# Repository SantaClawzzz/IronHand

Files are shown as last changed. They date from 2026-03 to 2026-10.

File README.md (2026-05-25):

# Ironhand keyboard

keyboard

A full-sized keyboard in ZMK. Features a colored TFT screen, encoder, bluetooth connection and a battery.<br>
Numpad is on the left side and switches are easily replaceable with hotswap sockets. Tarkov themed.

* Keyboard specs:
  * 1 nice!nano v2 or nrf52840 pro Micro devkit
  * 1 MCP23S17-E_SO
  * 102 switches (MX)
  * 102 DO-35 diodes (1N4148)
  * 60 100nF 0603 capacitors (Any 100nF)
  * 103 LEDs (WS2812-2020) [One LED under the MCU]
  * One 2000mAh 3.7V LiPo Battery [Bridge the Charging pads under nice!nano]
  * 1 battery connector (JST PH 2.0)
  * 1 0.96" TFT SPI screen
  * 1 encoder
  * 1 button (TL3305A, optional)

## Electronics

The PCB order can be expensive, mostly shipping due to the size. I recommend ordering at least 10 (5 is minimum).<br>
The soldering is mostly fine, hotswap sockets and capacitors are easy but the LEDs are a pain.<br>
My recommendation:
* Solder one corner of the 4 pads on the entire row
* Take a LED and match the polarity
* Solder only by the corner for the entire row
* Then go backwards and solder the same side other corner, turn it and do the other side
  * Easier to do one side at a time
  * Holding the solder iron in the right hand do the right side of the LED
  * Then turn it 180 degrees and solder the other side
  * But to each their own
* the MCP soldering is basically the same, do one corner, align it, then solder the rest of the pins
* Keep in mind that the devkit has a pad under it that needs to be bridged to charge faster if you have a battery bigger than 500mAh!
* Also there is a LED under the devkit on the PCB, solder them first then the devkit on it.
* Otherwise without a desolder gun, you're gonna have a bad time.

## Mechanics

If you wish to change the project files, go ahead. It was designed in Fusion.
Printed with PETG and mostly default settings.
Two halves were attached with a metal plate and staples melted into the PETG halves.

## Firmware

* Connect USB-C
* Open ***Actions*** tab in this github repository
* Download the firmware <br>
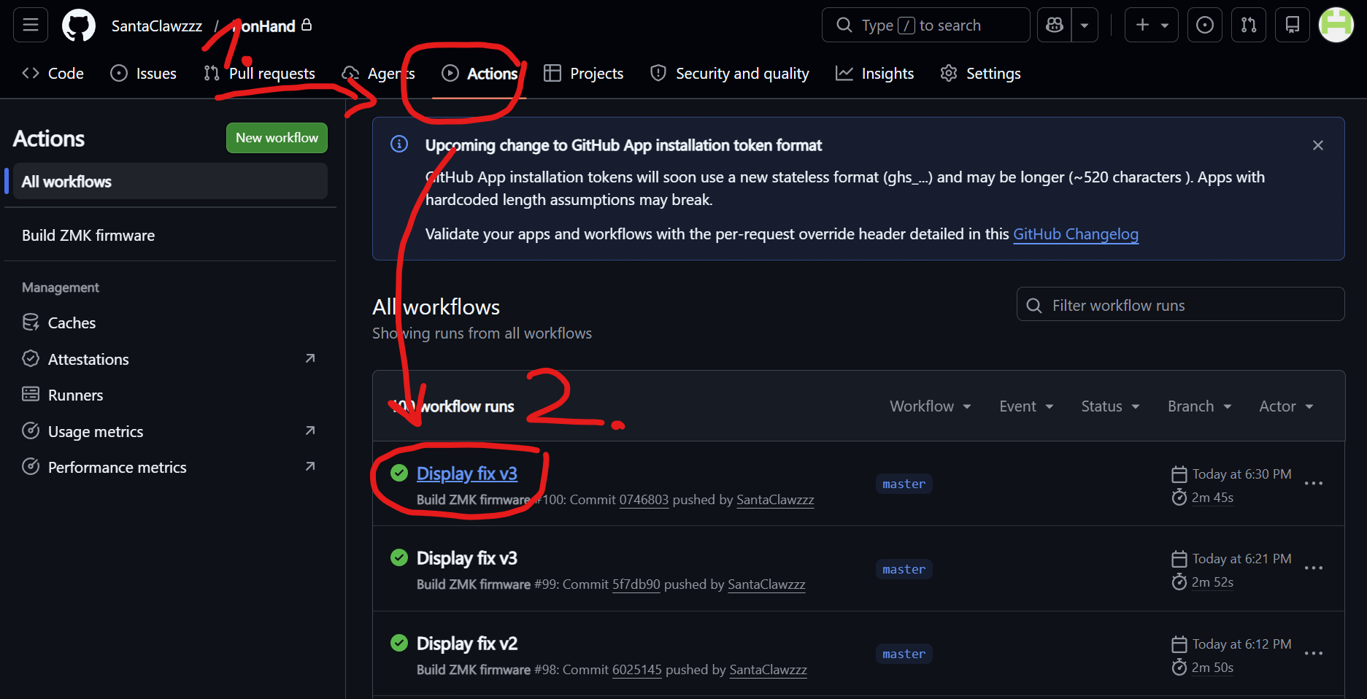
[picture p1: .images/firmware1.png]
firmware1

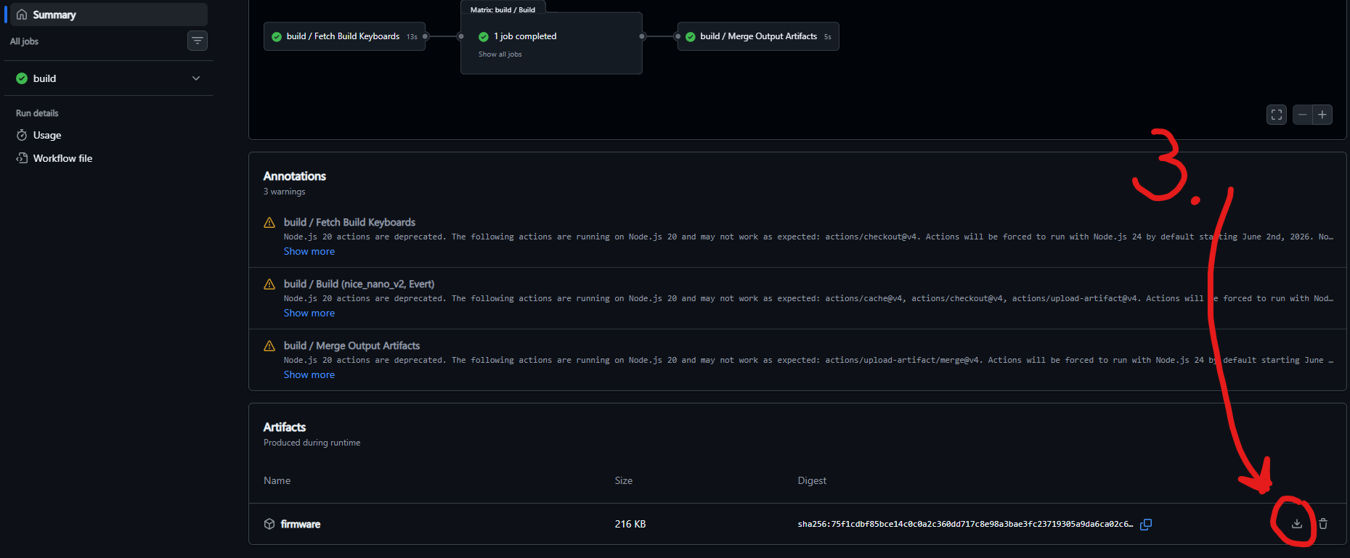
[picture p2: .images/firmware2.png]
firmware2

* Double press the reset button on the keyboard and drop the file into the file system
  * If you are in bootloader the red LED will constantly blink (nrf pro Micro devkit)

## Notes to consider when building custom keyboard

Read the documentation thoroughly, the directory of the files is VERY IMPORTANT.<br>
It's much more restrict than QMK so it will take some time.<br>
Just try to get it to compile wihtout much code and then start adding features.

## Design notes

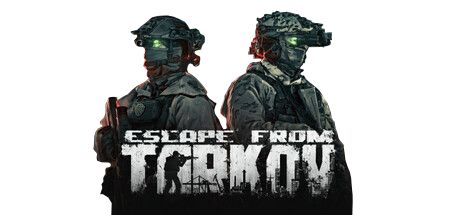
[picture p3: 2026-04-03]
Electronics/v1/Expo/escapefromtarkov.jpg

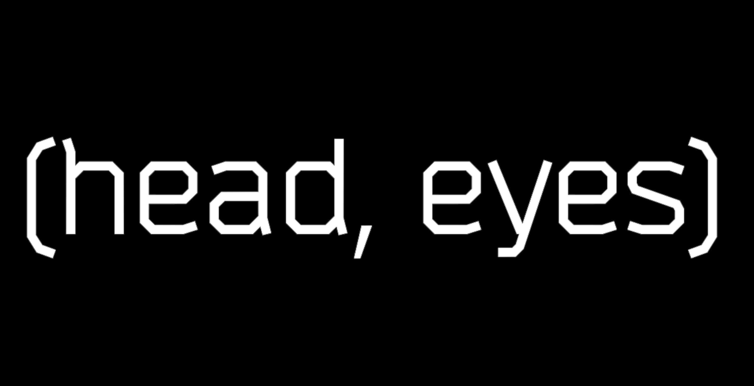
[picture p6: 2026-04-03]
Electronics/v1/Expo/headeyes.png

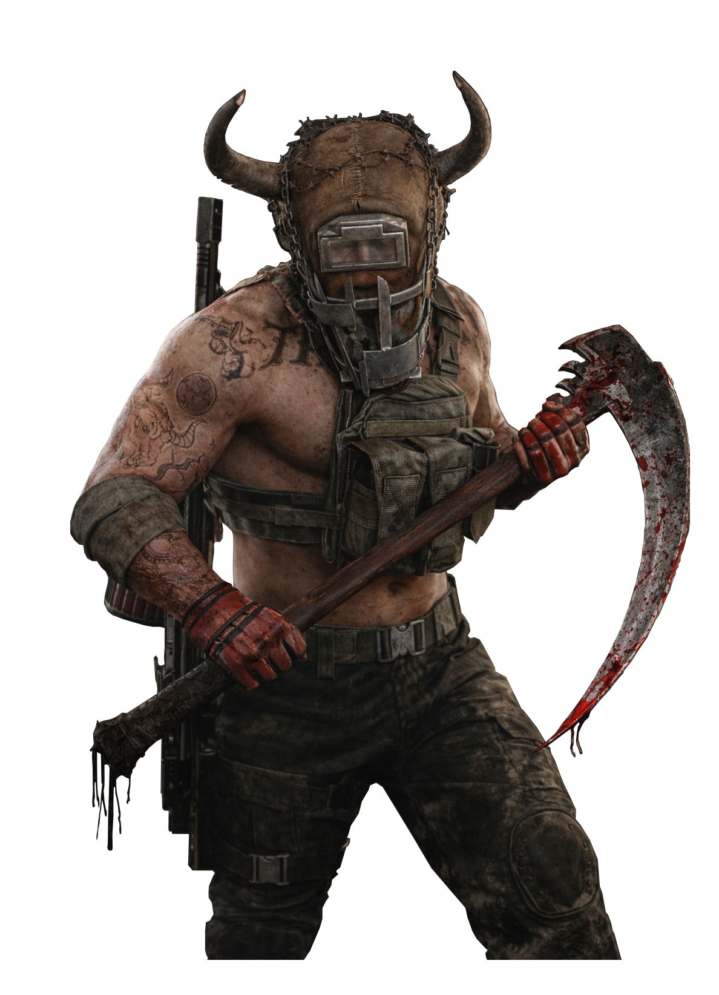
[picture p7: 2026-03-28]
Electronics/v1/Expo/killa.jpg

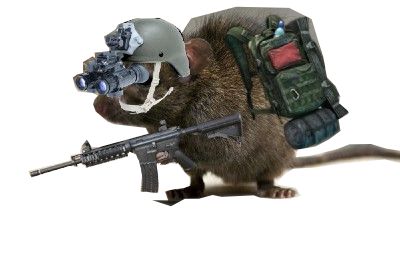
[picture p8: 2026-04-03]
Electronics/v1/Expo/Rat.jpg

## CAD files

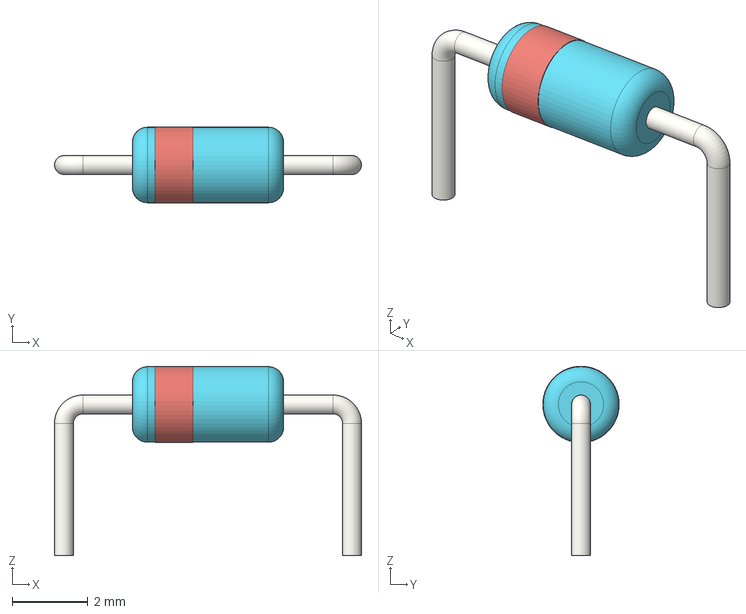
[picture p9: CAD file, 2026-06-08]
Electronics/v1/IronHand_v1/Components/3DModels/Diode_DO-35.step
8.12 x 2.02 x 5.01 mm

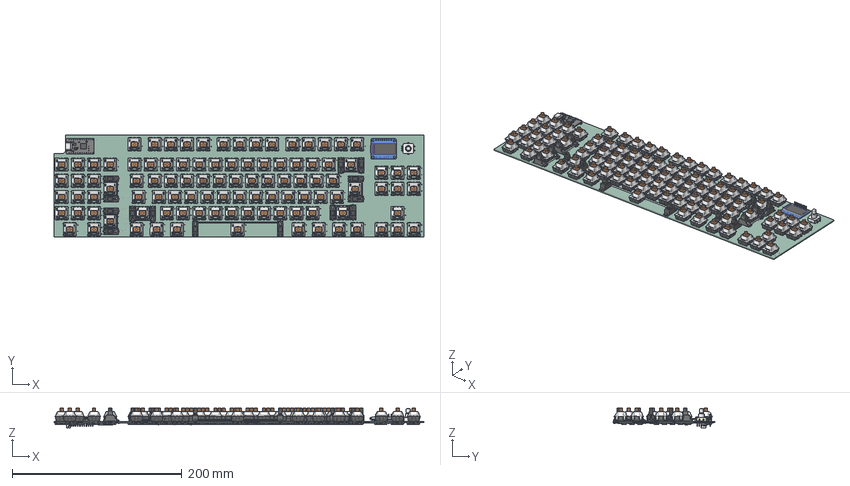
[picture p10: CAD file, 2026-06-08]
Electronics/v1/IronHand_v1/Output/pcb.step
435.3 x 120.0 x 23.1 mm
Hotswap_MX x 102
MX_PCB x 102
PinHeader_1x12_P2.54mm_Vertical.step
User Library-TYPE-C-31-M-14.step
MICRO_603 resistor 102
MICRO_stackable header pin x 12
MICRO_stackable header 12
micro_crystal 5x3
MICRO_led
micro_MIC5219
Stabilizer_MX_6.25u
Stabilizer_MX_2.00u x 6
PinHeader_1x08_P2.54mm_Vertical
0.96 - IPS LCD - ST7735S
Case003
Mount001
Case002
Case01
Leg001
Shaft002 x 2
Shaft001 x 2
Shaft003 x 2
Leg002 x 2
Leg003 x 2
Leg005 x 2
Leg004
Mount002
Diode_DO-35 x 3
SOIC28-W_MC_MCH
JST_PH_B2B-PH-K_1x02_P2.00mm_Vertical
SW_SPST_TL3305A
IronHand_v1_PCB

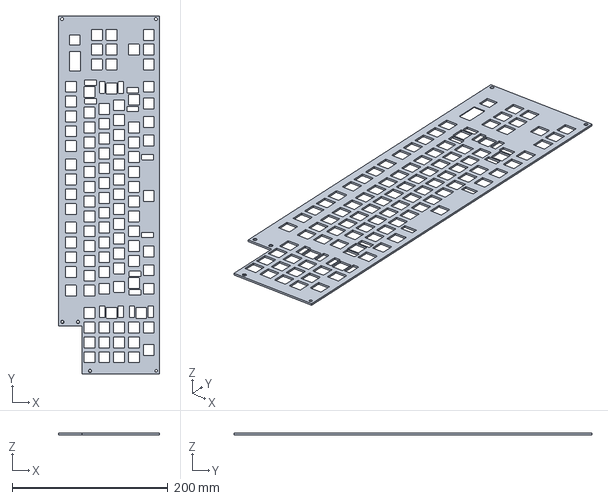
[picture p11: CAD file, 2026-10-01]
Mechnaics/PCBPlate.step
129.7 x 460.0 x 2.00 mm

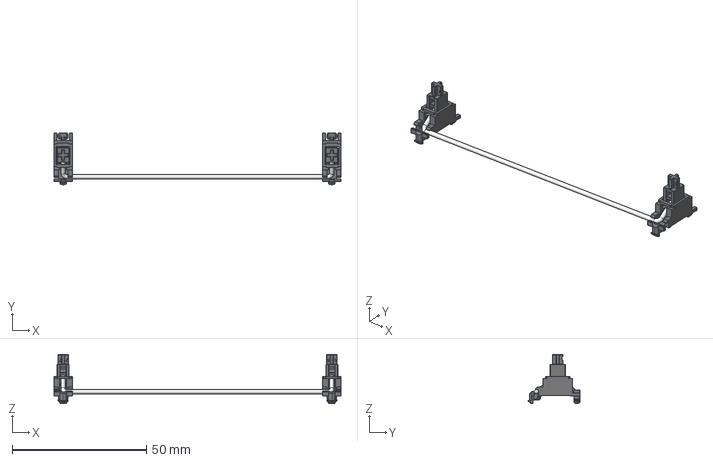
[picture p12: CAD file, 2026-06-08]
Electronics/v1/IronHand_v1/Components/3DModels/Stabilizer_MX_6.25u.step
106.8 x 19.2 x 18.3 mm

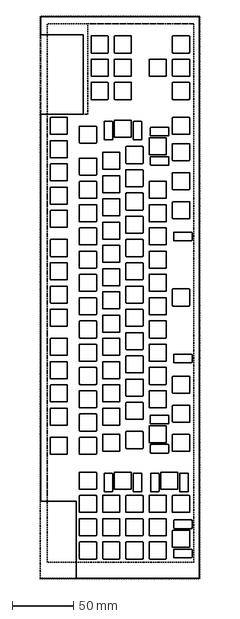
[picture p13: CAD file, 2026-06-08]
Electronics/v1/IronHand_v1/Output/IronHandPCBPlate.dxf
131.0 x 461.0 mm

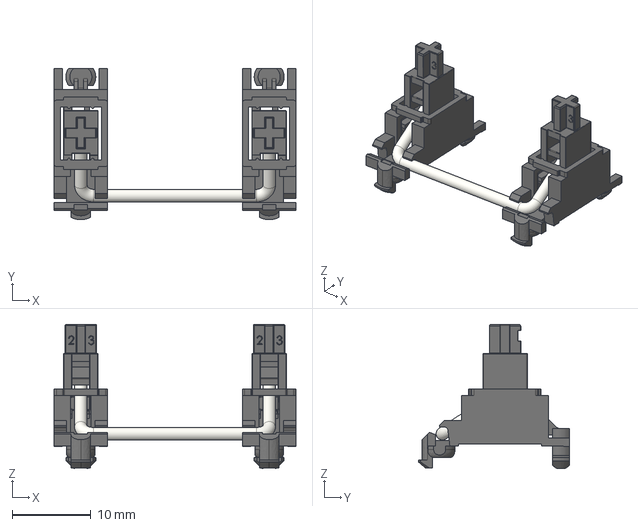
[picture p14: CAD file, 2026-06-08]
Electronics/v1/IronHand_v1/Components/3DModels/Stabilizer_MX_2.00u.step
30.7 x 19.2 x 18.3 mm

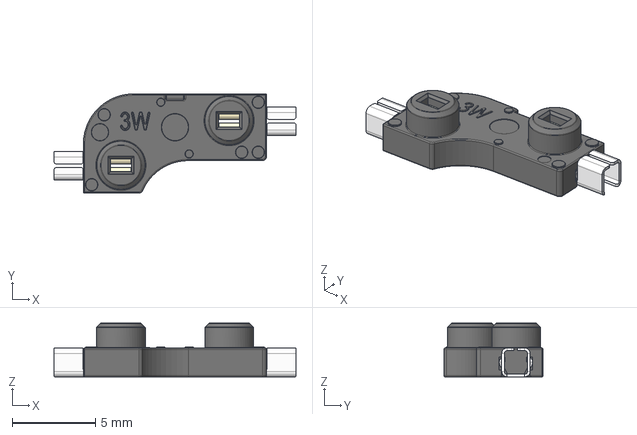
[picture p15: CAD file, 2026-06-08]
Electronics/v1/IronHand_v1/Components/3DModels/Hotswap_MX.step
14.5 x 5.95 x 3.22 mm

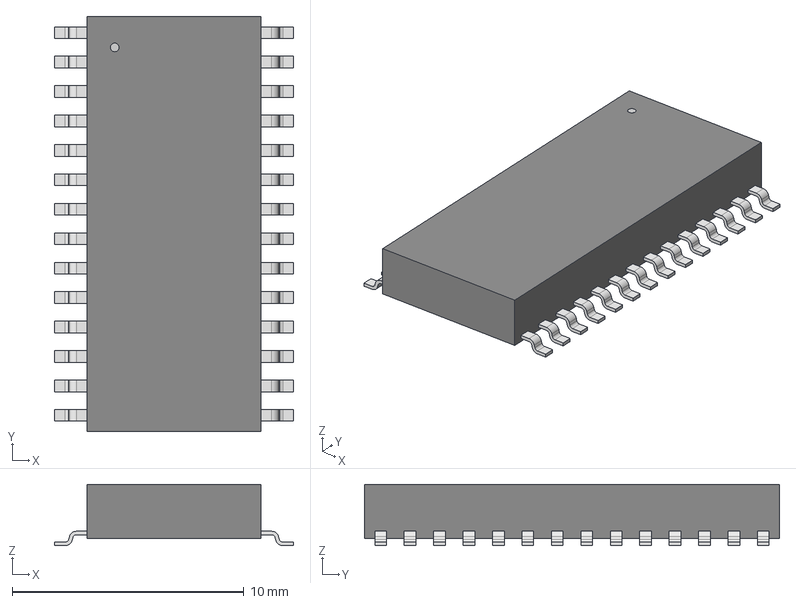
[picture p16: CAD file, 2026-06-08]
Electronics/v1/IronHand_v1/Components/3DModels/SOIC28-W_MC_MCH.step
10.3 x 17.9 x 2.64 mm

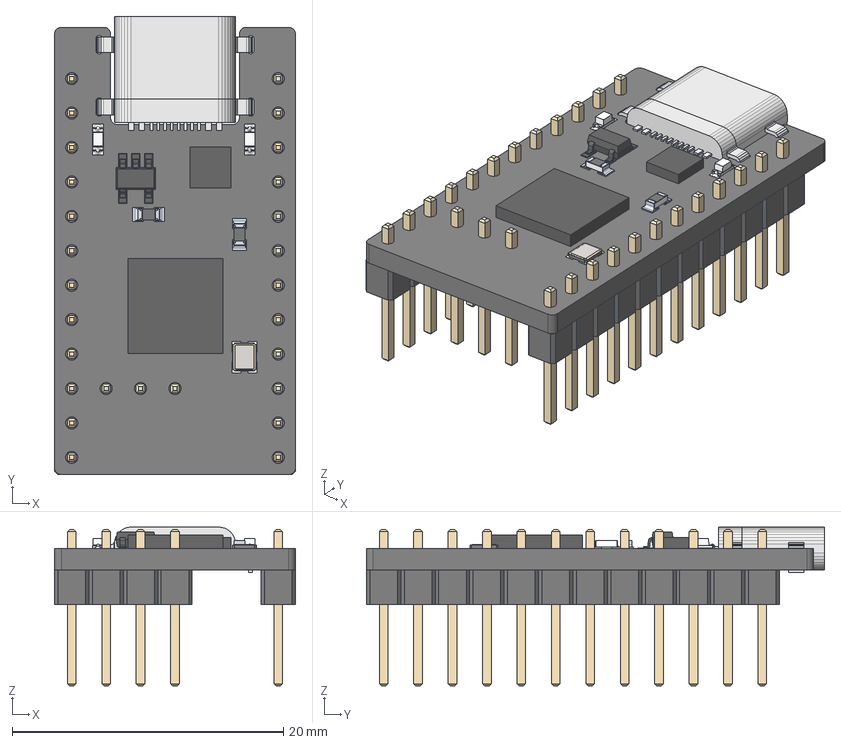
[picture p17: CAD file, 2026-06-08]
Electronics/v1/IronHand_v1/Components/3DModels/Nice_Nano_V2.step
17.8 x 33.8 x 11.7 mm
PinHeader_1x12_P2.54mm_Vertical.step
User Library-TYPE-C-31-M-14.step
MICRO_603 resistor 102
MICRO_stackable header pin x 12
MICRO_stackable header 12
micro_crystal 5x3
MICRO_led
micro_MIC5219

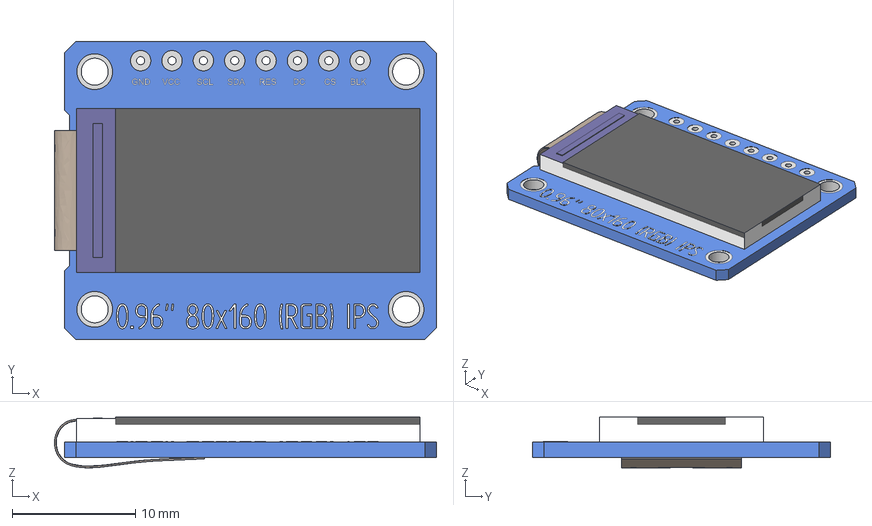
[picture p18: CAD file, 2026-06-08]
Electronics/v1/IronHand_v1/Components/3DModels/0.96 - IPS LCD - ST7735S.stp
30.9 x 24.1 x 4.11 mm

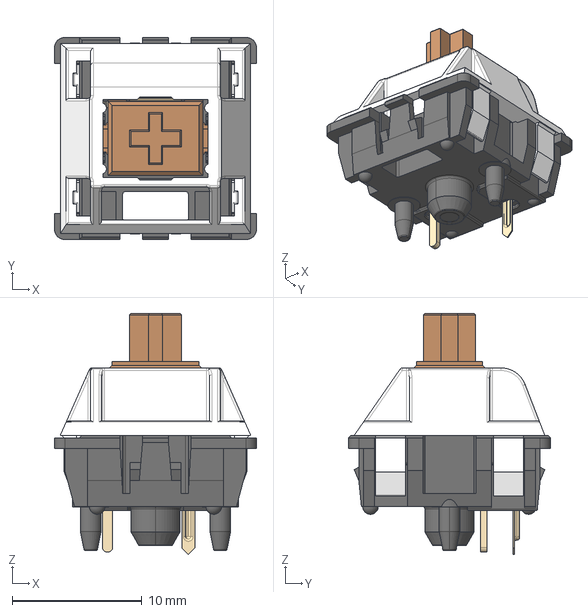
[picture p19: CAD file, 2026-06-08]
Electronics/v1/IronHand_v1/Components/3DModels/MX_PCB.step
15.6 x 15.6 x 18.6 mm

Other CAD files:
Mechnaics/PCBPlate.f3d

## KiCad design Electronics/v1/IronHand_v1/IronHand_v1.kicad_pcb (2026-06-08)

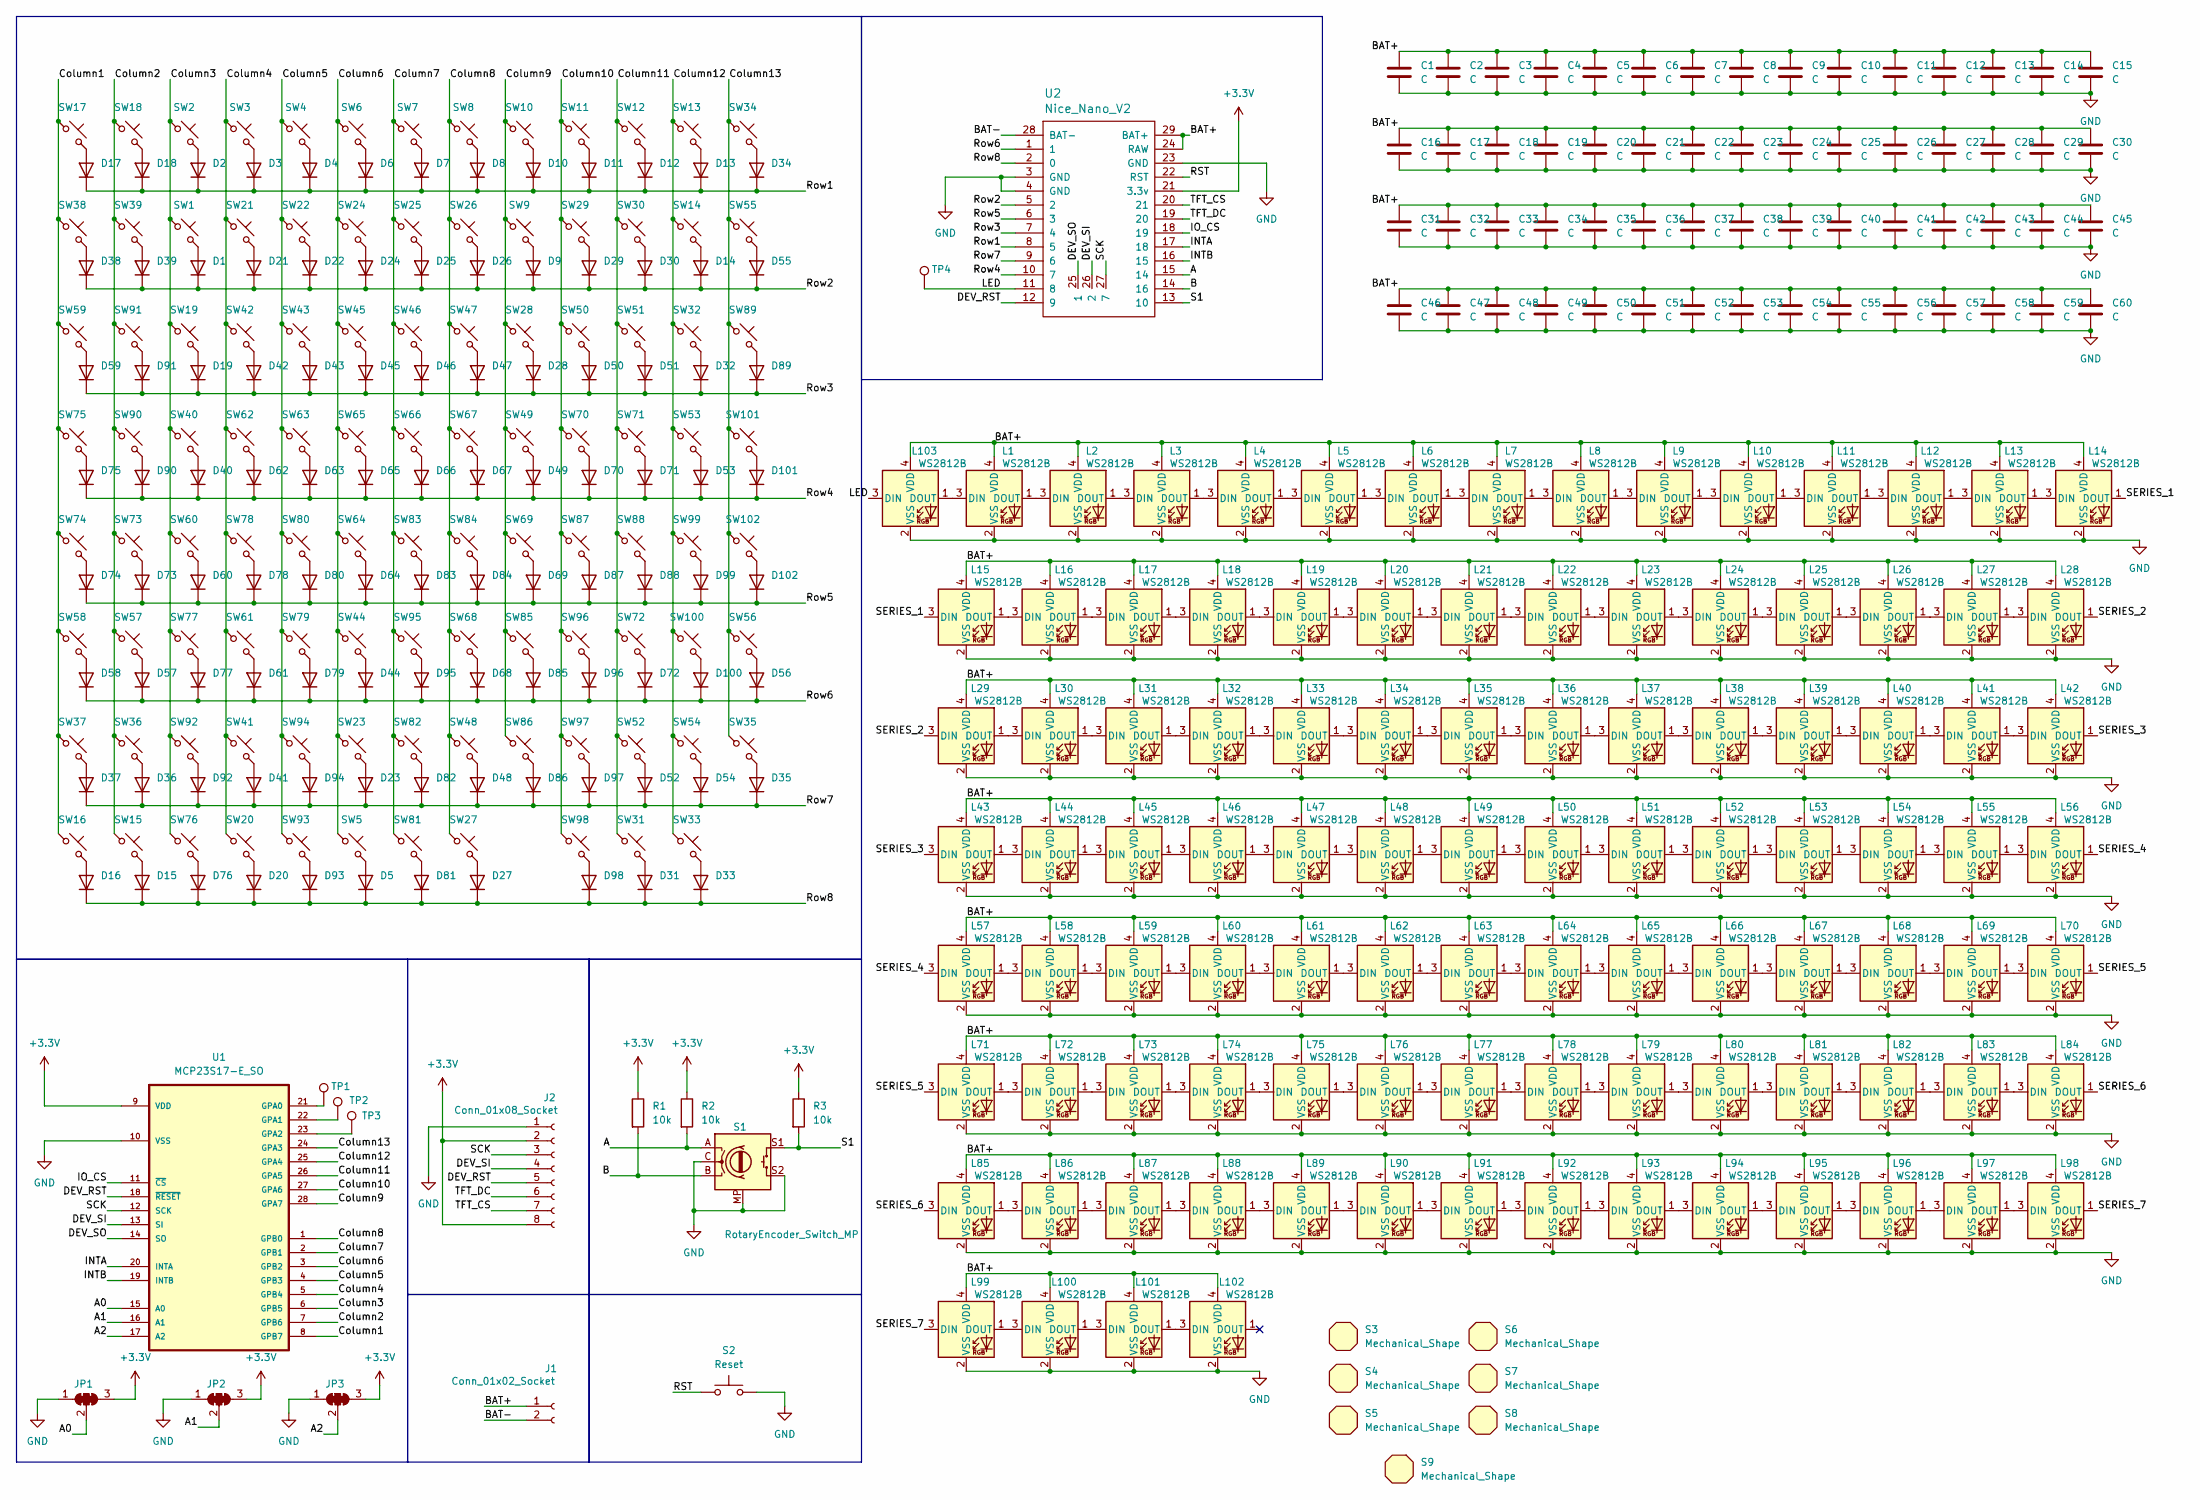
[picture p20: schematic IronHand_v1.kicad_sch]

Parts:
C1, C2, C3, C4, C5, C6, C7, C8, C9, C10, C11, C12, C13, C14, C15, C16, C17, C18, C19, C20, C21, C22, C23, C24, C25, C26, C27, C28, C29, C30, C31, C32, C33, C34, C35, C36, C37, C38, C39, C40, C41, C42, C43, C44, C45, C46, C47, C48, C49, C50, C51, C52, C53, C54, C55, C56, C57, C58, C59, C60: C; C_0603_1608Metric_Pad1.08x0.95mm_HandSolder
D1, D2, D3, D4, D5, D6, D7, D8, D9, D10, D11, D12, D13, D14, D15, D16, D17, D18, D19, D20, D21, D22, D23, D24, D25, D26, D27, D28, D29, D30, D31, D32, D33, D34, D35, D36, D37, D38, D39, D40, D41, D42, D43, D44, D45, D46, D47, D48, D49, D50, D51, D52, D53, D54, D55, D56, D57, D58, D59, D60, D61, D62, D63, D64, D65, D66, D67, D68, D69, D70, D71, D72, D73, D74, D75, D76, D77, D78, D79, D80, D81, D82, D83, D84, D85, D86, D87, D88, D89, D90, D91, D92, D93, D94, D95, D96, D97, D98, D99, D100, D101, D102: D; Diode_DO-35
J1: Conn_01x02_Socket; JST_PH_B2B-PH-K_1x02_P2.00mm_Vertical
J2: Conn_01x08_Socket; PinHeader_1x08_P2.54mm_Vertical
JP1, JP2, JP3: SolderJumper_3_Bridged123; SolderJumper-3_P2.0mm_Open_TrianglePad1.0x1.5mm_NumberLabels
L1, L2, L3, L4, L5, L6, L7, L8, L9, L10, L11, L12, L13, L14, L15, L16, L17, L18, L19, L20, L21, L22, L23, L24, L25, L26, L27, L28, L29, L30, L31, L32, L33, L34, L35, L36, L37, L38, L39, L40, L41, L42, L43, L44, L45, L46, L47, L48, L49, L50, L51, L52, L53, L54, L55, L56, L57, L58, L59, L60, L61, L62, L63, L64, L65, L66, L67, L68, L69, L70, L71, L72, L73, L74, L75, L76, L77, L78, L79, L80, L81, L82, L83, L84, L85, L86, L87, L88, L89, L90, L91, L92, L93, L94, L95, L96, L97, L98, L99, L100, L101, L102, L103: WS2812B; LED_WS2812B-2020_PLCC4_2.0x2.0mm
R1, R2, R3: 10k; R_0603_1608Metric_Pad0.98x0.95mm_HandSolder
S1: RotaryEncoder_Switch_MP; RotaryEncoder_Alps_EC12E-Switch_Vertical_H20mm
S2: Reset; SW_SPST_TL3305A
S3, S4, S5, S7, S8, S9: Mechanical_Shape; Stabilizer_MX_2.00u
S6: Mechanical_Shape; Stabilizer_MX_6.25u
SW1, SW2, SW3, SW4, SW5, SW6, SW7, SW8, SW9, SW10, SW11, SW12, SW13, SW14, SW15, SW16, SW17, SW18, SW19, SW20, SW21, SW22, SW23, SW24, SW25, SW26, SW27, SW28, SW29, SW30, SW31, SW33, SW34, SW35, SW36, SW37, SW38, SW41, SW42, SW43, SW44, SW45, SW46, SW47, SW48, SW49, SW50, SW51, SW52, SW54, SW55, SW56, SW57, SW58, SW59, SW60, SW61, SW62, SW63, SW64, SW65, SW66, SW67, SW68, SW69, SW70, SW71, SW72, SW73, SW74, SW75, SW78, SW79, SW80, SW81, SW82, SW83, SW84, SW85, SW86, SW87, SW89, SW91, SW99, SW100, SW101, SW102: SW_Push_45deg; Hotswap_MX_1.00u
SW32: SW_Push_45deg; Hotswap_MX_1.75u
SW39, SW90: SW_Push_45deg; Hotswap_MX_2.00u
SW40, SW92, SW93, SW94, SW96, SW97, SW98: SW_Push_45deg; Hotswap_MX_1.25u
SW53: SW_Push_45deg; Hotswap_MX_ISOEnter
SW76, SW77: SW_Push_45deg; Hotswap_MX_2.00u_90deg
SW88: SW_Push_45deg; Hotswap_MX_2.75u
SW95: SW_Push_45deg; Hotswap_MX_6.25u
TP1, TP2, TP3, TP4: TestPoint; TestPoint_Keystone_5015_Micro_Mini
U1: MCP23S17-E_SO; SOIC127P1030X265-28N
U2: Nice_Nano_V2

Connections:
+3.3V: J2.2, J2.8, JP1.3 (B), JP2.3 (B), JP3.3 (B), R1.1, R2.1, R3.1, U1.9 (VDD), U2.21 (3.3v)
/A: R2.2, S1.A, U2.15 (14)
/A0: JP1.2 (C), U1.15 (A0)
/A1: JP2.2 (C), U1.16 (A1)
/A2: JP3.2 (C), U1.17 (A2)
/B: R1.2, S1.B, U2.14 (16)
/BAT+: C1.1, C2.1, C3.1, C4.1, C5.1, C6.1, C7.1, C8.1, C9.1, C10.1, C11.1, C12.1, C13.1, C14.1, C15.1, C16.1, C17.1, C18.1, C19.1, C20.1, C21.1, C22.1, C23.1, C24.1, C25.1, C26.1, C27.1, C28.1, C29.1, C30.1, C31.1, C32.1, C33.1, C34.1, C35.1, C36.1, C37.1, C38.1, C39.1, C40.1, C41.1, C42.1, C43.1, C44.1, C45.1, C46.1, C47.1, C48.1, C49.1, C50.1, C51.1, C52.1, C53.1, C54.1, C55.1, C56.1, C57.1, C58.1, C59.1, C60.1, J1.1, L1.4 (VDD), L2.4 (VDD), L3.4 (VDD), L4.4 (VDD), L5.4 (VDD), L6.4 (VDD), L7.4 (VDD), L8.4 (VDD), L9.4 (VDD), L10.4 (VDD), L11.4 (VDD), L12.4 (VDD), L13.4 (VDD), L14.4 (VDD), L15.4 (VDD), L16.4 (VDD), L17.4 (VDD), L18.4 (VDD), L19.4 (VDD), L20.4 (VDD), L21.4 (VDD), L22.4 (VDD), L23.4 (VDD), L24.4 (VDD), L25.4 (VDD), L26.4 (VDD), L27.4 (VDD), L28.4 (VDD), L29.4 (VDD), L30.4 (VDD), L31.4 (VDD), L32.4 (VDD), L33.4 (VDD), L34.4 (VDD), L35.4 (VDD), L36.4 (VDD), L37.4 (VDD), L38.4 (VDD), L39.4 (VDD), L40.4 (VDD), L41.4 (VDD), L42.4 (VDD), L43.4 (VDD), L44.4 (VDD), L45.4 (VDD), L46.4 (VDD), L47.4 (VDD), L48.4 (VDD), L49.4 (VDD), L50.4 (VDD), L51.4 (VDD), L52.4 (VDD), L53.4 (VDD), L54.4 (VDD), L55.4 (VDD), L56.4 (VDD), L57.4 (VDD), L58.4 (VDD), L59.4 (VDD), L60.4 (VDD), L61.4 (VDD), L62.4 (VDD), L63.4 (VDD), L64.4 (VDD), L65.4 (VDD), L66.4 (VDD), L67.4 (VDD), L68.4 (VDD), L69.4 (VDD), L70.4 (VDD), L71.4 (VDD), L72.4 (VDD), L73.4 (VDD), L74.4 (VDD), L75.4 (VDD), L76.4 (VDD), L77.4 (VDD), L78.4 (VDD), L79.4 (VDD), L80.4 (VDD), L81.4 (VDD), L82.4 (VDD), L83.4 (VDD), L84.4 (VDD), L85.4 (VDD), L86.4 (VDD), L87.4 (VDD), L88.4 (VDD), L89.4 (VDD), L90.4 (VDD), L91.4 (VDD), L92.4 (VDD), L93.4 (VDD), L94.4 (VDD), L95.4 (VDD), L96.4 (VDD), L97.4 (VDD), L98.4 (VDD), L99.4 (VDD), L100.4 (VDD), L101.4 (VDD), L102.4 (VDD), L103.4 (VDD), U2.24 (RAW), U2.29 (BAT+)
/BAT-: J1.2, U2.28 (BAT-)
/Column1: SW16.1, SW17.1, SW37.1, SW38.1, SW58.1, SW59.1, SW74.1, SW75.1, U1.8 (GPB7)
/Column2: SW15.1, SW18.1, SW36.1, SW39.1, SW57.1, SW73.1, SW90.1, SW91.1, U1.7 (GPB6)
/Column3: SW1.1, SW2.1, SW19.1, SW40.1, SW60.1, SW76.1, SW77.1, SW92.1, U1.6 (GPB5)
/Column4: SW3.1, SW20.1, SW21.1, SW41.1, SW42.1, SW61.1, SW62.1, SW78.1, U1.5 (GPB4)
/Column5: SW4.1, SW22.1, SW43.1, SW63.1, SW79.1, SW80.1, SW93.1, SW94.1, U1.4 (GPB3)
/Column6: SW5.1, SW6.1, SW23.1, SW24.1, SW44.1, SW45.1, SW64.1, SW65.1, U1.3 (GPB2)
/Column7: SW7.1, SW25.1, SW46.1, SW66.1, SW81.1, SW82.1, SW83.1, SW95.1, U1.2 (GPB1)
/Column8: SW8.1, SW26.1, SW27.1, SW47.1, SW48.1, SW67.1, SW68.1, SW84.1, U1.1 (GPB0)
/Column9: SW9.1, SW10.1, SW28.1, SW49.1, SW69.1, SW85.1, SW86.1, U1.28 (GPA7)
/Column10: SW11.1, SW29.1, SW50.1, SW70.1, SW87.1, SW96.1, SW97.1, SW98.1, U1.27 (GPA6)
/Column11: SW12.1, SW30.1, SW31.1, SW51.1, SW52.1, SW71.1, SW72.1, SW88.1, U1.26 (GPA5)
/Column12: SW13.1, SW14.1, SW32.1, SW33.1, SW53.1, SW54.1, SW99.1, SW100.1, U1.25 (GPA4)
/Column13: SW34.1, SW35.1, SW55.1, SW56.1, SW89.1, SW101.1, SW102.1, U1.24 (GPA3)
/DEV_RST: J2.5, U1.18 (~RESET), U2.12 (9)
/DEV_SI: J2.4, U1.13 (SI), U2.26 (2)
/DEV_SO: U1.14 (SO), U2.25 (1)
/INTA: U1.20 (INTA), U2.17 (18)
/INTB: U1.19 (INTB), U2.16 (15)
/IO_CS: U1.11 (~CS), U2.18 (19)
/LED: L103.3 (DIN), TP4.1 (1_1), U2.11 (8)
/RST: S2.1, U2.22 (RST)
/Row1: D2.1 (K), D3.1 (K), D4.1 (K), D6.1 (K), D7.1 (K), D8.1 (K), D10.1 (K), D11.1 (K), D12.1 (K), D13.1 (K), D17.1 (K), D18.1 (K), D34.1 (K), U2.8 (5)
/Row2: D1.1 (K), D9.1 (K), D14.1 (K), D21.1 (K), D22.1 (K), D24.1 (K), D25.1 (K), D26.1 (K), D29.1 (K), D30.1 (K), D38.1 (K), D39.1 (K), D55.1 (K), U2.5 (2)
/Row3: D19.1 (K), D28.1 (K), D32.1 (K), D42.1 (K), D43.1 (K), D45.1 (K), D46.1 (K), D47.1 (K), D50.1 (K), D51.1 (K), D59.1 (K), D89.1 (K), D91.1 (K), U2.7 (4)
/Row4: D40.1 (K), D49.1 (K), D53.1 (K), D62.1 (K), D63.1 (K), D65.1 (K), D66.1 (K), D67.1 (K), D70.1 (K), D71.1 (K), D75.1 (K), D90.1 (K), D101.1 (K), U2.10 (7)
/Row5: D60.1 (K), D64.1 (K), D69.1 (K), D73.1 (K), D74.1 (K), D78.1 (K), D80.1 (K), D83.1 (K), D84.1 (K), D87.1 (K), D88.1 (K), D99.1 (K), D102.1 (K), U2.6 (3)
/Row6: D44.1 (K), D56.1 (K), D57.1 (K), D58.1 (K), D61.1 (K), D68.1 (K), D72.1 (K), D77.1 (K), D79.1 (K), D85.1 (K), D95.1 (K), D96.1 (K), D100.1 (K), U2.1
/Row7: D23.1 (K), D35.1 (K), D36.1 (K), D37.1 (K), D41.1 (K), D48.1 (K), D52.1 (K), D54.1 (K), D82.1 (K), D86.1 (K), D92.1 (K), D94.1 (K), D97.1 (K), U2.9 (6)
/Row8: D5.1 (K), D15.1 (K), D16.1 (K), D20.1 (K), D27.1 (K), D31.1 (K), D33.1 (K), D76.1 (K), D81.1 (K), D93.1 (K), D98.1 (K), U2.2 (0)
/S1: R3.2, S1.S1, U2.13 (10)
/SCK: J2.3, U1.12 (SCK), U2.27 (7)
/SERIES_1: L14.1 (DOUT), L15.3 (DIN)
/SERIES_2: L28.1 (DOUT), L29.3 (DIN)
/SERIES_3: L42.1 (DOUT), L43.3 (DIN)
/SERIES_4: L56.1 (DOUT), L57.3 (DIN)
/SERIES_5: L70.1 (DOUT), L71.3 (DIN)
/SERIES_6: L84.1 (DOUT), L85.3 (DIN)
/SERIES_7: L98.1 (DOUT), L99.3 (DIN)
/TFT_CS: J2.7, U2.20 (21)
/TFT_DC: J2.6, U2.19 (20)
GND: C1.2, C2.2, C3.2, C4.2, C5.2, C6.2, C7.2, C8.2, C9.2, C10.2, C11.2, C12.2, C13.2, C14.2, C15.2, C16.2, C17.2, C18.2, C19.2, C20.2, C21.2, C22.2, C23.2, C24.2, C25.2, C26.2, C27.2, C28.2, C29.2, C30.2, C31.2, C32.2, C33.2, C34.2, C35.2, C36.2, C37.2, C38.2, C39.2, C40.2, C41.2, C42.2, C43.2, C44.2, C45.2, C46.2, C47.2, C48.2, C49.2, C50.2, C51.2, C52.2, C53.2, C54.2, C55.2, C56.2, C57.2, C58.2, C59.2, C60.2, J2.1, JP1.1 (A), JP2.1 (A), JP3.1 (A), L1.2 (VSS), L2.2 (VSS), L3.2 (VSS), L4.2 (VSS), L5.2 (VSS), L6.2 (VSS), L7.2 (VSS), L8.2 (VSS), L9.2 (VSS), L10.2 (VSS), L11.2 (VSS), L12.2 (VSS), L13.2 (VSS), L14.2 (VSS), L15.2 (VSS), L16.2 (VSS), L17.2 (VSS), L18.2 (VSS), L19.2 (VSS), L20.2 (VSS), L21.2 (VSS), L22.2 (VSS), L23.2 (VSS), L24.2 (VSS), L25.2 (VSS), L26.2 (VSS), L27.2 (VSS), L28.2 (VSS), L29.2 (VSS), L30.2 (VSS), L31.2 (VSS), L32.2 (VSS), L33.2 (VSS), L34.2 (VSS), L35.2 (VSS), L36.2 (VSS), L37.2 (VSS), L38.2 (VSS), L39.2 (VSS), L40.2 (VSS), L41.2 (VSS), L42.2 (VSS), L43.2 (VSS), L44.2 (VSS), L45.2 (VSS), L46.2 (VSS), L47.2 (VSS), L48.2 (VSS), L49.2 (VSS), L50.2 (VSS), L51.2 (VSS), L52.2 (VSS), L53.2 (VSS), L54.2 (VSS), L55.2 (VSS), L56.2 (VSS), L57.2 (VSS), L58.2 (VSS), L59.2 (VSS), L60.2 (VSS), L61.2 (VSS), L62.2 (VSS), L63.2 (VSS), L64.2 (VSS), L65.2 (VSS), L66.2 (VSS), L67.2 (VSS), L68.2 (VSS), L69.2 (VSS), L70.2 (VSS), L71.2 (VSS), L72.2 (VSS), L73.2 (VSS), L74.2 (VSS), L75.2 (VSS), L76.2 (VSS), L77.2 (VSS), L78.2 (VSS), L79.2 (VSS), L80.2 (VSS), L81.2 (VSS), L82.2 (VSS), L83.2 (VSS), L84.2 (VSS), L85.2 (VSS), L86.2 (VSS), L87.2 (VSS), L88.2 (VSS), L89.2 (VSS), L90.2 (VSS), L91.2 (VSS), L92.2 (VSS), L93.2 (VSS), L94.2 (VSS), L95.2 (VSS), L96.2 (VSS), L97.2 (VSS), L98.2 (VSS), L99.2 (VSS), L100.2 (VSS), L101.2 (VSS), L102.2 (VSS), L103.2 (VSS), S1.C, S1.MP, S1.S2, S2.2, U1.10 (VSS), U2.3 (GND), U2.4 (GND), U2.23 (GND)
unnamed: D1.2 (A), SW1.2
unnamed: D2.2 (A), SW2.2
unnamed: D3.2 (A), SW3.2
unnamed: D4.2 (A), SW4.2
unnamed: D5.2 (A), SW5.2
unnamed: D6.2 (A), SW6.2
unnamed: D7.2 (A), SW7.2
unnamed: D8.2 (A), SW8.2
unnamed: D9.2 (A), SW9.2
unnamed: D10.2 (A), SW10.2
unnamed: D11.2 (A), SW11.2
unnamed: D12.2 (A), SW12.2
unnamed: D13.2 (A), SW13.2
unnamed: D14.2 (A), SW14.2
unnamed: D15.2 (A), SW15.2
unnamed: D16.2 (A), SW16.2
unnamed: D17.2 (A), SW17.2
unnamed: D18.2 (A), SW18.2
unnamed: D19.2 (A), SW19.2
unnamed: D20.2 (A), SW20.2
unnamed: D21.2 (A), SW21.2
unnamed: D22.2 (A), SW22.2
unnamed: D23.2 (A), SW23.2
unnamed: D24.2 (A), SW24.2
unnamed: D25.2 (A), SW25.2
unnamed: D26.2 (A), SW26.2
unnamed: D27.2 (A), SW27.2
unnamed: D28.2 (A), SW28.2
unnamed: D29.2 (A), SW29.2
unnamed: D30.2 (A), SW30.2
unnamed: D31.2 (A), SW31.2
unnamed: D32.2 (A), SW32.2
unnamed: D33.2 (A), SW33.2
unnamed: D34.2 (A), SW34.2
unnamed: D35.2 (A), SW35.2
unnamed: D36.2 (A), SW36.2
unnamed: D37.2 (A), SW37.2
unnamed: D38.2 (A), SW38.2
unnamed: D39.2 (A), SW39.2
unnamed: D40.2 (A), SW40.2
unnamed: D41.2 (A), SW41.2
unnamed: D42.2 (A), SW42.2
unnamed: D43.2 (A), SW43.2
unnamed: D44.2 (A), SW44.2
unnamed: D45.2 (A), SW45.2
unnamed: D46.2 (A), SW46.2
unnamed: D47.2 (A), SW47.2
unnamed: D48.2 (A), SW48.2
unnamed: D49.2 (A), SW49.2
unnamed: D50.2 (A), SW50.2
unnamed: D51.2 (A), SW51.2
unnamed: D52.2 (A), SW52.2
unnamed: D53.2 (A), SW53.2
unnamed: D54.2 (A), SW54.2
unnamed: D55.2 (A), SW55.2
unnamed: D56.2 (A), SW56.2
unnamed: D57.2 (A), SW57.2
unnamed: D58.2 (A), SW58.2
unnamed: D59.2 (A), SW59.2
unnamed: D60.2 (A), SW60.2
unnamed: D61.2 (A), SW61.2
unnamed: D62.2 (A), SW62.2
unnamed: D63.2 (A), SW63.2
unnamed: D64.2 (A), SW64.2
unnamed: D65.2 (A), SW65.2
unnamed: D66.2 (A), SW66.2
unnamed: D67.2 (A), SW67.2
unnamed: D68.2 (A), SW68.2
unnamed: D69.2 (A), SW69.2
unnamed: D70.2 (A), SW70.2
unnamed: D71.2 (A), SW71.2
unnamed: D72.2 (A), SW72.2
unnamed: D73.2 (A), SW73.2
unnamed: D74.2 (A), SW74.2
unnamed: D75.2 (A), SW75.2
unnamed: D76.2 (A), SW76.2
unnamed: D77.2 (A), SW77.2
unnamed: D78.2 (A), SW78.2
unnamed: D79.2 (A), SW79.2
unnamed: D80.2 (A), SW80.2
unnamed: D81.2 (A), SW81.2
unnamed: D82.2 (A), SW82.2
unnamed: D83.2 (A), SW83.2
unnamed: D84.2 (A), SW84.2
unnamed: D85.2 (A), SW85.2
unnamed: D86.2 (A), SW86.2
unnamed: D87.2 (A), SW87.2
unnamed: D88.2 (A), SW88.2
unnamed: D89.2 (A), SW89.2
unnamed: D90.2 (A), SW90.2
unnamed: D91.2 (A), SW91.2
unnamed: D92.2 (A), SW92.2
unnamed: D93.2 (A), SW93.2
unnamed: D94.2 (A), SW94.2
unnamed: D95.2 (A), SW95.2
unnamed: D96.2 (A), SW96.2
unnamed: D97.2 (A), SW97.2
unnamed: D98.2 (A), SW98.2
unnamed: D99.2 (A), SW99.2
unnamed: D100.2 (A), SW100.2
unnamed: D101.2 (A), SW101.2
unnamed: D102.2 (A), SW102.2
unnamed: L1.3 (DIN), L103.1 (DOUT)
unnamed: L1.1 (DOUT), L2.3 (DIN)
unnamed: L2.1 (DOUT), L3.3 (DIN)
unnamed: L3.1 (DOUT), L4.3 (DIN)
unnamed: L4.1 (DOUT), L5.3 (DIN)
unnamed: L5.1 (DOUT), L6.3 (DIN)
unnamed: L6.1 (DOUT), L7.3 (DIN)
unnamed: L7.1 (DOUT), L8.3 (DIN)
unnamed: L8.1 (DOUT), L9.3 (DIN)
unnamed: L9.1 (DOUT), L10.3 (DIN)
unnamed: L10.1 (DOUT), L11.3 (DIN)
unnamed: L11.1 (DOUT), L12.3 (DIN)
unnamed: L12.1 (DOUT), L13.3 (DIN)
unnamed: L13.1 (DOUT), L14.3 (DIN)
unnamed: L15.1 (DOUT), L16.3 (DIN)
unnamed: L16.1 (DOUT), L17.3 (DIN)
unnamed: L17.1 (DOUT), L18.3 (DIN)
unnamed: L18.1 (DOUT), L19.3 (DIN)
unnamed: L19.1 (DOUT), L20.3 (DIN)
unnamed: L20.1 (DOUT), L21.3 (DIN)
unnamed: L21.1 (DOUT), L22.3 (DIN)
unnamed: L22.1 (DOUT), L23.3 (DIN)
unnamed: L23.1 (DOUT), L24.3 (DIN)
unnamed: L24.1 (DOUT), L25.3 (DIN)
unnamed: L25.1 (DOUT), L26.3 (DIN)
unnamed: L26.1 (DOUT), L27.3 (DIN)
unnamed: L27.1 (DOUT), L28.3 (DIN)
unnamed: L29.1 (DOUT), L30.3 (DIN)
unnamed: L30.1 (DOUT), L31.3 (DIN)
unnamed: L31.1 (DOUT), L32.3 (DIN)
unnamed: L32.1 (DOUT), L33.3 (DIN)
unnamed: L33.1 (DOUT), L34.3 (DIN)
unnamed: L34.1 (DOUT), L35.3 (DIN)
unnamed: L35.1 (DOUT), L36.3 (DIN)
unnamed: L36.1 (DOUT), L37.3 (DIN)
unnamed: L37.1 (DOUT), L38.3 (DIN)
unnamed: L38.1 (DOUT), L39.3 (DIN)
unnamed: L39.1 (DOUT), L40.3 (DIN)
unnamed: L40.1 (DOUT), L41.3 (DIN)
unnamed: L41.1 (DOUT), L42.3 (DIN)
unnamed: L43.1 (DOUT), L44.3 (DIN)
unnamed: L44.1 (DOUT), L45.3 (DIN)
unnamed: L45.1 (DOUT), L46.3 (DIN)
unnamed: L46.1 (DOUT), L47.3 (DIN)
unnamed: L47.1 (DOUT), L48.3 (DIN)
unnamed: L48.1 (DOUT), L49.3 (DIN)
unnamed: L49.1 (DOUT), L50.3 (DIN)
unnamed: L50.1 (DOUT), L51.3 (DIN)
unnamed: L51.1 (DOUT), L52.3 (DIN)
unnamed: L52.1 (DOUT), L53.3 (DIN)
unnamed: L53.1 (DOUT), L54.3 (DIN)
unnamed: L54.1 (DOUT), L55.3 (DIN)
unnamed: L55.1 (DOUT), L56.3 (DIN)
unnamed: L57.1 (DOUT), L58.3 (DIN)
unnamed: L58.1 (DOUT), L59.3 (DIN)
unnamed: L59.1 (DOUT), L60.3 (DIN)
unnamed: L60.1 (DOUT), L61.3 (DIN)
unnamed: L61.1 (DOUT), L62.3 (DIN)
unnamed: L62.1 (DOUT), L63.3 (DIN)
unnamed: L63.1 (DOUT), L64.3 (DIN)
unnamed: L64.1 (DOUT), L65.3 (DIN)
unnamed: L65.1 (DOUT), L66.3 (DIN)
unnamed: L66.1 (DOUT), L67.3 (DIN)
unnamed: L67.1 (DOUT), L68.3 (DIN)
unnamed: L68.1 (DOUT), L69.3 (DIN)
unnamed: L69.1 (DOUT), L70.3 (DIN)
unnamed: L71.1 (DOUT), L72.3 (DIN)
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

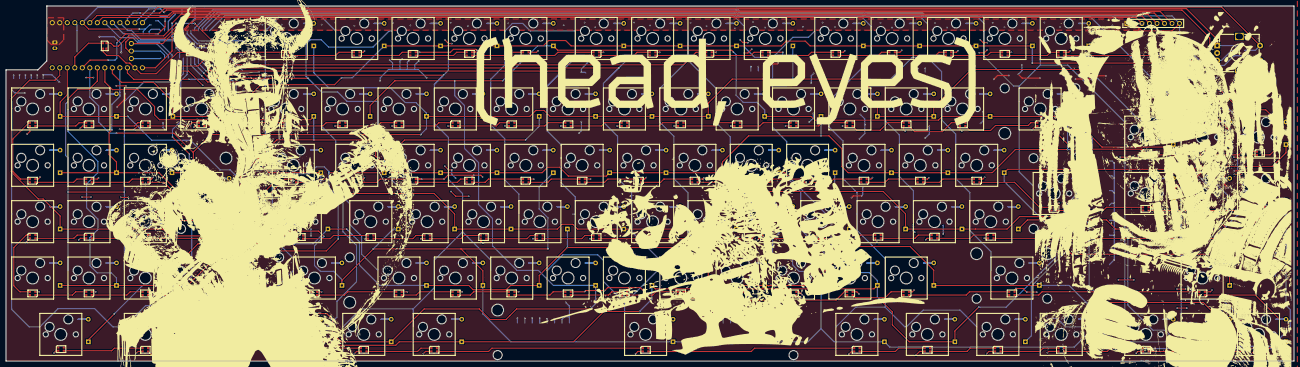
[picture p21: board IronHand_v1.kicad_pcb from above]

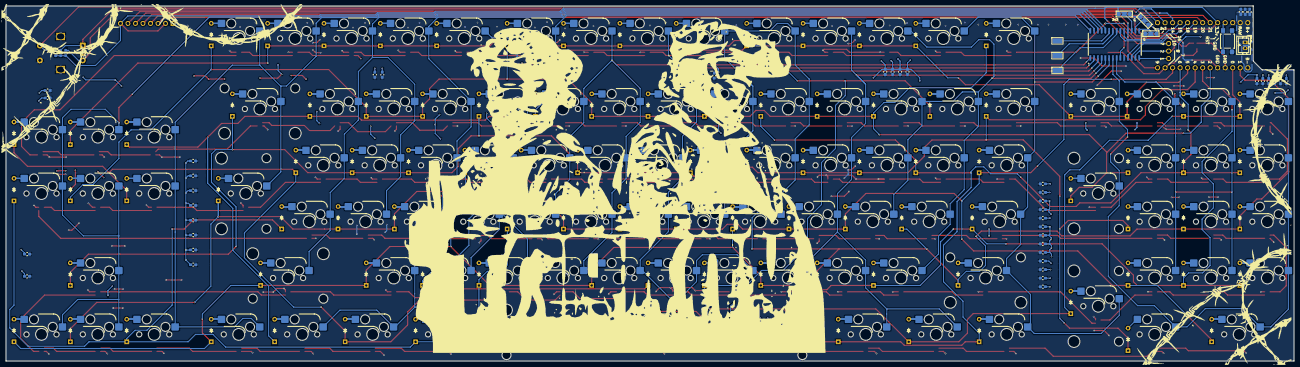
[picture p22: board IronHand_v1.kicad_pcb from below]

Board: 2 copper layers, 435.3 x 120.0 mm, 390 parts (174 on the bottom side), 249 nets.

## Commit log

2025-11-11 Added boards directory to conf as well
2025-11-11 Kconfig in config and boards in boards
2025-11-11 Added boards as well
2025-11-11 Removed shield option, opting to use just as board in config folder
2025-11-11 Added more boards@
2025-11-12 Adding boards folders
2025-11-12 boards folder add
2025-11-12 Pin enables
2025-11-12 Changes from nice60 board 1/2
2025-11-13 Added ext power and vbatt nodes
2025-11-13 Changed the board nice60 conf
2025-11-13 Removed the LED configs for now
2025-11-20 Changed board from nicenanov2 to nicenano
2026-04-03 v1 production
    [IronHand_v1-B_Adhesive.gbr, IronHand_v1-B_Cu.gbr, IronHand_v1-B_Mask.gbr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]
2026-04-20 v1 first test
    [IronHand_v1.kicad_sch]
2026-04-20 MCP driver push
2026-04-20 test insert
2026-04-20 inv, col, pwm
2026-05-20 WS2812 chain length increase
2026-05-20 Battery fix, ADC add in config
2026-05-20 ADC implemented and RGB_TOGGLE with encoder sel
2026-05-20 removed ADC, since battery.c not used, battery is code free
2026-05-22 Display and LEDs
2026-05-22 Switch to zmk_display_status_screen() for custom display
    Replaces the delayed-work SYS_INIT hack with the proper ZMK hook.
    ZMK calls zmk_display_status_screen() during display init so we own
    the screen from the start — no timing race, no 2s delay.
    Tarkov image renders as screen background via LV_EVENT_DRAW_MAIN;
    output, layer, and battery widgets are layered on top with transparent
    backgrounds.
2026-05-22 Remove battery widget — battery reporting is disabled
    ZMK_BATTERY_REPORTING=n means the battery widget is never compiled.
    Drop it from the custom status screen to fix the linker error.
2026-06-08 library added to project
    [0.96 - IPS LCD - ST7735S.stp, Diode_DO-35.step, Hotswap_MX.step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]
2026-10-01 Pushed Plate 3D exports
    [PCBPlate.f3d, PCBPlate.step]
2026-10-01 Plate stabilizer fix
    [PCBPlate.f3d, PCBPlate.step]
